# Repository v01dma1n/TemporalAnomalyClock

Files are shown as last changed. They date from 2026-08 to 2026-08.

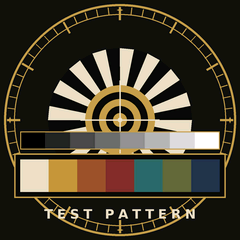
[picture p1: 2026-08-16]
images/photo_face_test_signal.png

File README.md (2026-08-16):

# Temporal Anomaly Clock

An ESP-IDF firmware for a round GC9A01 LCD turned NTP clock with a
twist: the displayed time doesn't just tell you the time, it visibly
speeds up, slows down, and occasionally runs backwards — while staying
exactly correct on average.

This is the IDF port of the Arduino-generation `temporal_anomaly_clock`
(originally a MAX6921-driven VFD tube clock), rebuilt on top of
[ESP32NTPClock2](https://github.com/v01dma1n/ESP32NTPClock2) and
[ESP32WiFi2](https://github.com/v01dma1n/ESP32WiFi2), aligned with the
architecture used by [MoodWhisperer](https://github.com/v01dma1n/MoodWhisperer).
Class names, extension points, and file layout mirror that project, so
switching between the two should feel familiar. The VFD tube is gone —
this generation targets a round pixel LCD instead — but the WiFi/NTP/
preferences engine underneath is the same one.

---

## Hardware

| Part | Role |
|---|---|
| ESP32-C3-MINI-1U | MCU (JCZN "ESP32-2424S012"-style integrated board) |
| GC9A01 | 1.28", 240×240 round IPS LCD, SPI |

Pinout (confirmed working on this board — no dedicated RST line, no
built-in touch used):

| Signal | GPIO |
|---|---|
| SPI SCLK | 6 |
| SPI MOSI | 7 |
| SPI CS | 10 |
| SPI DC | 2 |
| Backlight | 3 |
| RST | not connected — software reset only |

The panel needs a horizontal mirror at the LVGL display-config level
(`disp_cfg.rotation.mirror_x = true` in `disp_driver_gc9a01_round_clock.cpp`)
to render right-reading. This must be set in the `lvgl_port_display_cfg_t`
struct itself — a separate `esp_lcd_panel_mirror()` call made before
`lvgl_port_add_disp()` gets silently overwritten, since that function
re-applies orientation from `disp_cfg.rotation` internally.

---

## Project layout

```
TemporalAnomalyClock/
├── CMakeLists.txt
├── sdkconfig.defaults
├── partitions/
│   └── partitions.csv
├── components/
│   ├── esp32_ntp_clock/         # git submodule → ESP32NTPClock2 (the "engine")
│   ├── esp32_wifi/              # git submodule → ESP32WiFi2 (WiFi + prefs + portal)
│   └── esp32_ntp_clock_drivers/ # git submodule → ESP32NTPClockDrivers2
│       └── gc9a01/              # only this nested component is used — see below
└── main/                   # the application
    ├── main.cpp
    ├── temporal_anomaly_app.{h,cpp}
    ├── temporal_anomaly_preferences.{h,cpp}
    ├── temporal_anomaly_access_point_manager.{h,cpp}
    └── temporal_anomaly_time_source.{h,cpp}   # the "anomaly" itself — see Architecture
```

The GC9A01 display driver itself (`DispDriverGc9a01RoundClock`) and the
generic `IDisplayTimeProvider` interface it implements both live in the
shared [ESP32NTPClockDrivers2](https://github.com/v01dma1n/ESP32NTPClockDrivers2)
repo, under its `gc9a01/` nested component — not in `main/`. That
component is LVGL-based, unlike every other driver in that shared repo,
so it's kept separate and only pulled in by projects that explicitly opt
in (see that repo's README and this project's top-level `CMakeLists.txt`
for the `EXTRA_COMPONENT_DIRS`/`EXCLUDE_COMPONENTS` wiring this needs).

---

## Architecture

### 1. Engine (`components/esp32_ntp_clock`, `components/esp32_wifi`)

Same engine as MoodWhisperer: `BaseNtpClockApp`, `ClockFsmManager`,
`SceneManager`, `IDisplayDriver`, `BasePreferences`,
`BaseAccessPointManager`. See either project's submodule source for the
full interface surface — nothing about it is modified here.

### 2. Display driver (`components/esp32_ntp_clock_drivers/gc9a01/`)

`DispDriverGc9a01RoundClock` is deliberately generic and reusable — it has
no notion of "temporal anomaly," wobble, or chaos. It has two jobs on one
physical screen:

- **`IDisplayDriver` implementation** — satisfies the engine's
  character-grid contract (`setChar`, segment masks, frame buffers) so
  the boot/WiFi/NTP/AP-mode status messages the engine already knows how
  to generate keep working unmodified. There's no real segment glass
  behind it: the plain-text path just pushes to an LVGL status label.
  Segment-specific methods are accepted but no-op — nothing in this app
  drives segment-style scene animations (the `SceneManager` playlist is
  empty).
- **The watch face** — an analog clock (hour/minute/second hands as
  `lv_line` widgets, tight-bounding-box sized per update rather than
  full-screen, to keep SPI traffic and redraw regions small) plus a
  six-slot digital readout (one `lv_label` per digit, since proportional
  font glyphs aren't equal-width and a single shared label visibly
  drifts sideways as digits change).

The two live on separate LVGL screens (`_bootScreen` / `_faceScreen`),
switched via `lv_scr_load()`. `showClockFace()` flips between them once
the FSM reaches `RUNNING_NORMAL`.

Each tick, the driver just asks *"what time is it"* via a small interface
it defines and owns no opinion about the answer to:

```cpp
// i_display_time_provider.h
struct DisplayTime { int hour, minute; double second; int wday, mday; };
class IDisplayTimeProvider {
public:
    virtual DisplayTime getDisplayTime() = 0;
};
```

`setTimeProvider(IDisplayTimeProvider*)` wires in whatever answers that
question. A different app could plug in a provider that just calls
`localtime_r()` on real time and get an ordinary accurate clock out of
this same driver, unmodified.

### 3. The anomaly (`main/temporal_anomaly_time_source.{h,cpp}`)

`TemporalAnomalyTimeSource : IDisplayTimeProvider` is what actually makes
this clock a *temporal anomaly* clock rather than a plain one — the
sinusoidal wobble and the chaos levels (see below) both live here,
entirely decoupled from LVGL/rendering. `TemporalAnomalyClockApp` owns the
instance and wires it into the display driver in `setupHardware()`.

### 4. Application (`main/temporal_anomaly_*`)

- `TemporalAnomalyPreferences : BasePreferences` — adds startup-animation
  toggle, OpenWeatherMap key/city, and the anomaly wobble period/amplitude
  on top of `BaseConfig`.
- `TemporalAnomalyAccessPointManager : BaseAccessPointManager` — adds the
  matching rows to the captive portal.
- `TemporalAnomalyClockApp : BaseNtpClockApp` — owns the display driver,
  the time source, the display manager, and the shared `WeatherManager`.
  No scene playlist; `loop()` toggles `showClockFace()` directly off FSM
  state and feeds fresh weather readings into the display driver each
  tick.

---

## The temporal anomaly

The watch face's *displayed* time fluctuates — speeding up, slowing
down, and occasionally running backwards — while staying exactly
correct on average. Modeled as a sinusoidal rate around real time:

```
rate(t) = 1 + A·sin(2π·t/P)
```

Integrating that rate gives the displayed-time offset from real time,
which is periodic with period `P`. Whenever `P` evenly divides 60, the
offset at `t+60` exactly equals the offset at `t` — meaning displayed
time gains exactly as much as it loses over *any* 60-second window, not
just ones aligned to a particular phase. This holds regardless of
amplitude: with `A > 1` the rate swings negative for part of each cycle
and the hands visibly reverse before catching back up.

Configurable in the portal:

- **Anomaly wobble period (sec)** — should divide 60 evenly (e.g. 5, 6,
  10, 12, 15, 20, 30, 60) for the exact-average guarantee; not enforced
  by the form.
- **Anomaly wobble amplitude ×100** — 100 = steady real time, >100 lets
  the hands run backwards for part of each cycle. Default 140 (rate
  swings from −0.4x to 2.4x).

Only the watch-face rendering is perturbed — real system time (NTP
sync, logs, preferences, `time()`) is untouched.

---

## Chaos anomaly levels

A second, independent perturbation layered additively on top of the
sinusoidal wobble above. Unlike that system, chaos mode makes **no**
accuracy guarantee — it's a damped random walk, not a periodic
function:

- occasional random "kicks" to a velocity, with probability and
  magnitude both scaling with level (so low levels stutter rarely,
  high levels kick often and hard), hard-capped so a run of
  same-direction kicks can't accumulate into runaway speed;
- weak mean-reversion pulling that velocity back toward zero — more
  weakly at higher levels, so excursions last longer as the level
  increases;
- a gentle spring pulling the accumulated offset back toward real
  time, so even at max chaos the clock stays roughly near real time
  over long periods without any hard guarantee.

Configurable in the portal:

- **Anomaly chaos level (0-11)** — 0 off, 1-3 subtle speed variations
  and occasional skips/repeats, 4-7 noticeable accelerations/
  decelerations/short reversals, 8-10 extreme and largely
  unpredictable speed changes, 11 fully random — the displayed second
  is re-rolled to a random 0-59 value once per real elapsed second
  (hour/minute keep tracking real time; only the second progression
  goes chaotic).

Both perturbation systems only affect the watch-face rendering, same
as the sinusoidal wobble — real system time is never touched.

### Why the hands are flat, not tapered

The hands were originally drawn as 6 stacked line segments per hand
(18 total) to fake a tapered width + color gradient — `lv_line` can't
taper or gradient a single stroke natively. Under fast chaos motion
this became a real bottleneck: measurement showed LVGL ticks meant to
fire every 30ms were arriving 150-300ms late *even at chaos level 0*,
meaning the redraw cost is a constant per-tick problem that's simply
invisible when the hand barely moves between frames. Neither raising
the SPI clock (20→40MHz) nor disabling the dial's live gradient
background changed this — cutting the segment count from 6 to 1 per
hand did, roughly 3x. Hands are now a single flat-color segment each;
this MCU/display combo has a real throughput ceiling well under the
30Hz the tick timer assumes.

---

## Weather

Pulls current temperature (°F) and relative humidity from
[OpenWeatherMap](https://openweathermap.org/) via the shared
`WeatherManager`, and rotates them into the digital readout row every
5 seconds alongside the time (`TIME → TEMPERATURE → HUMIDITY → TIME →
...`). The analog hands keep ticking continuously regardless of what
the readout row is showing.

Configure in the portal:

- **OpenWeatherMap API Key** — free account at openweathermap.org.
- **OWM City** — comma-separated as the OWM API expects, e.g.
  `South Plainfield,NJ,US` or `Warsaw,PL`. A plain space instead of
  commas will fail to geocode (404).

The temperature/humidity rotation stays on TIME only until the first
successful fetch — it never shows stale or zeroed weather.

---

## Photo face

A fourth rotation slot alongside TIME/TEMPERATURE/HUMIDITY: full-face
240×240 images (`main/photo_face_*_data.cpp`, round-robin via
`setPhotos()`) with a one-pass CRT-style scan-bar sweep and flicker,
wired in via `DispDriverGc9a01RoundClock`. The driver itself has no
opinion on the images' content — same generic seam as
`IDisplayTimeProvider` — so swapping in a different photo is just a
matter of running `scripts/convert_photo.py path/to/image.jpg
var_name photo_face.h` against a new square source image and
rebuilding. Most of the rotation is Google Gemini-generated portraits;
the "test signal" slot (`photo_face_test_signal`) is instead a
code-synthesized art-deco TV test card (PIL, see
`scripts/gen_deco_test_card.py`), not AI-generated art.

---

## Captive portal and timezone handling

Same split as MoodWhisperer:

1. First boot / no credentials stored → AP mode → user enters SSID/
   password and picks a timezone from the dropdown (defaults to UTC).
2. After WiFi connects, `ClockFsmManager` tries automatic timezone
   detection via IP geolocation if the stored timezone is blank, but
   the portal always has the final say.

The portal is open (no password) at `http://192.168.4.1/`, with every
DNS query on the AP network redirected there so phones/laptops pop the
captive-portal sheet automatically.

This app doesn't wire up a physical AP-trigger button (unlike
MoodWhisperer's BOOT-button hold) — the only way to force AP mode is
`BootManager`'s built-in double-reset detection: two resets within
~10 seconds. Worth knowing when iterating with `idf.py flash` followed
by a manual reset for testing — back-to-back resets land you in the
portal.

---

## Build

Requirements: ESP-IDF ≥ 5.1, targeting `esp32c3`.

The `components/esp32_ntp_clock`, `components/esp32_wifi`, and
`components/esp32_ntp_clock_drivers` directories are git submodules.
Initialise them after cloning:

```bash
git clone --recurse-submodules https://github.com/v01dma1n/TemporalAnomalyClock.git
# or, inside an existing clone:
git submodule update --init
```

Then build and flash:

```bash
. $IDF_PATH/export.sh
cd TemporalAnomalyClock
idf.py set-target esp32c3
idf.py build
idf.py -p /dev/ttyACM0 flash
```

`idf.py monitor` needs an interactive TTY; from a non-interactive shell,
read the serial port directly (e.g. via `pyserial`) instead.

First boot: the board comes up in AP mode (no credentials stored).
Connect to the open `temporal-anomaly` network, the captive portal
opens, fill in WiFi + timezone + (optionally) OpenWeatherMap + anomaly
wobble settings, save.

---

## Known issues

- No external RTC on this board — NTP-only timekeeping. Per
  MoodWhisperer's own notes on the same engine: an NTP timeout with no
  RTC fitted can drop the FSM back into AP_MODE even when WiFi is up
  (`clock_fsm_manager.cpp`, `NTP_SYNC` case). Not yet reproduced on this
  project, but worth knowing if the clock ever seems to bounce back to
  setup mode unexpectedly on a flaky network.
- The "anomaly level" field in the original Arduino app's preferences
  was dead code there (stored but never actually read). The chaos
  levels feature (above) reuses the name but is a from-scratch
  implementation with real behavior behind it, not a revival of that
  old field.

---

## License

MIT (matches the upstream Arduino projects and MoodWhisperer).

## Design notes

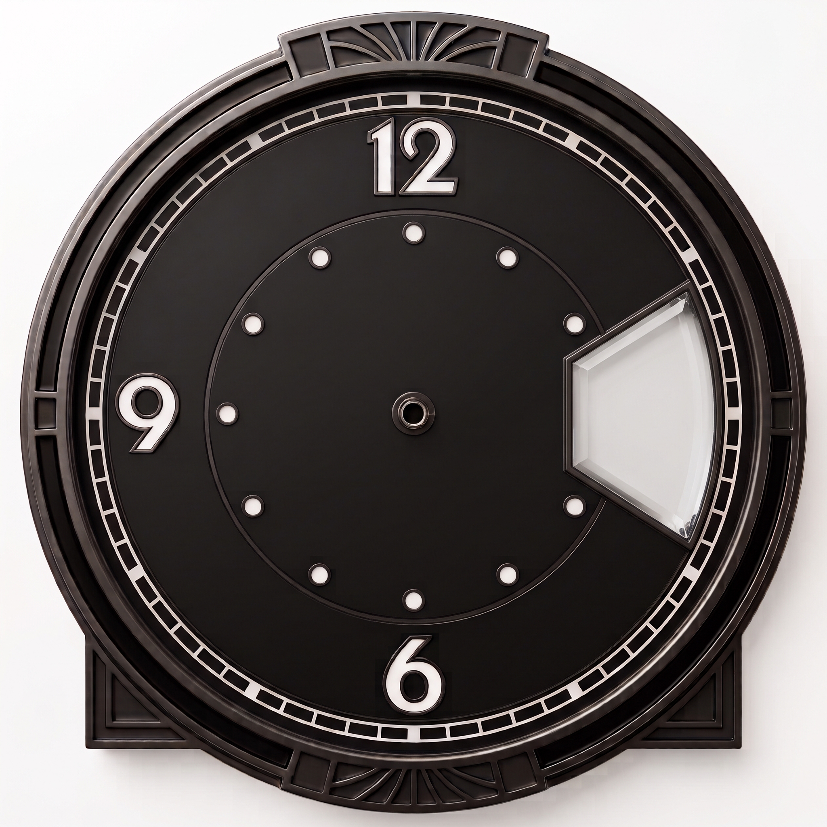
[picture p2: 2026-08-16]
images/input/Gemini_Generated_Image_clock_face_no_arms_date_crystal.jpeg

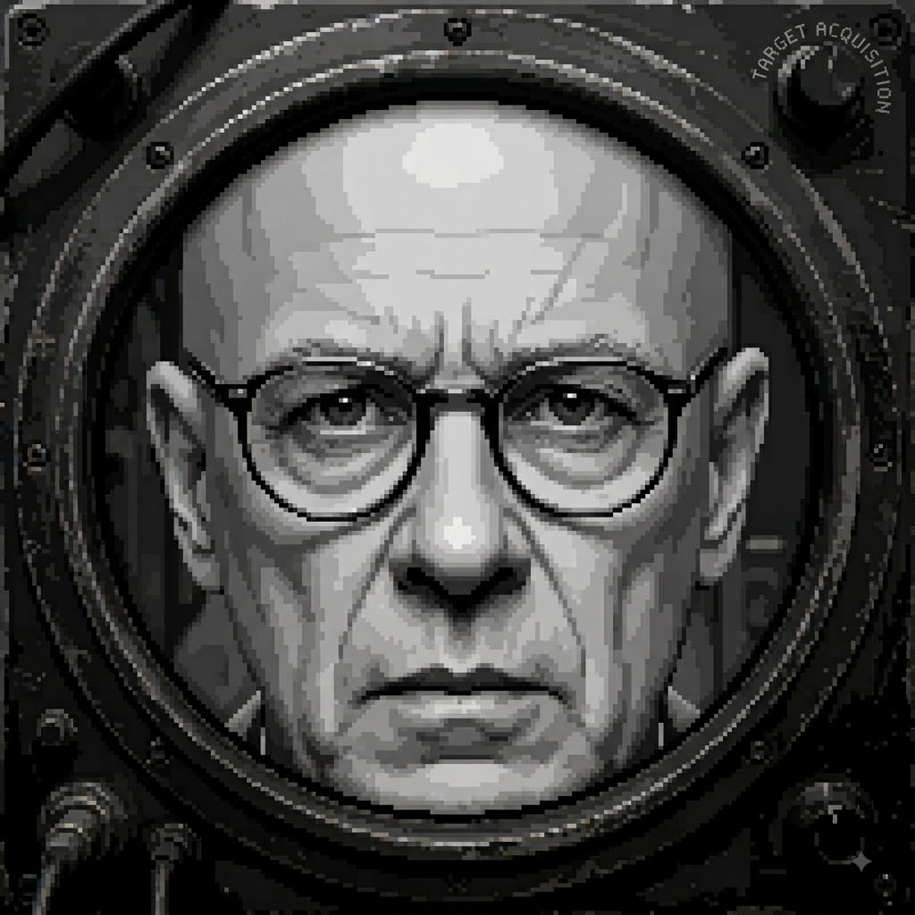
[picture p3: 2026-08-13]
images/input/Gemini_Generated_bald_man.jpeg

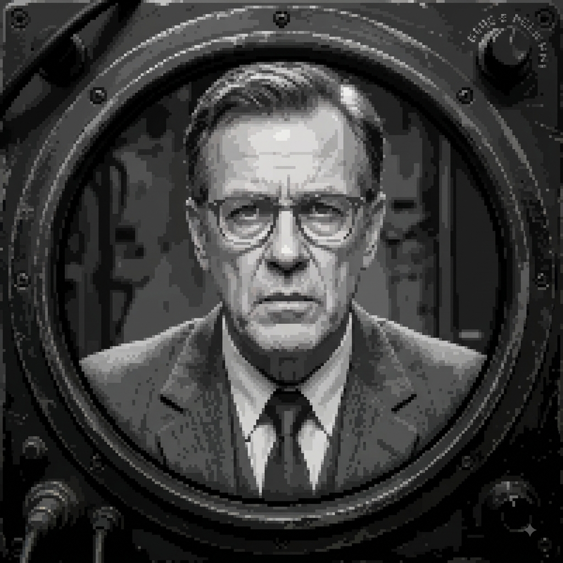
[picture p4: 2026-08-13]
images/input/Gemini_Generated_Image_wl5qerwl5qerwl5q.png

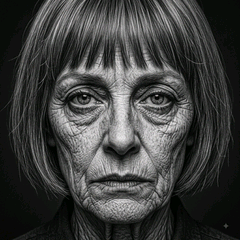
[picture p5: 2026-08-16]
images/photo_face_warden.png

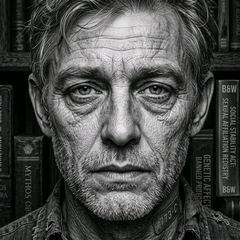
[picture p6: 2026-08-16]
images/photo_face_archivist.png

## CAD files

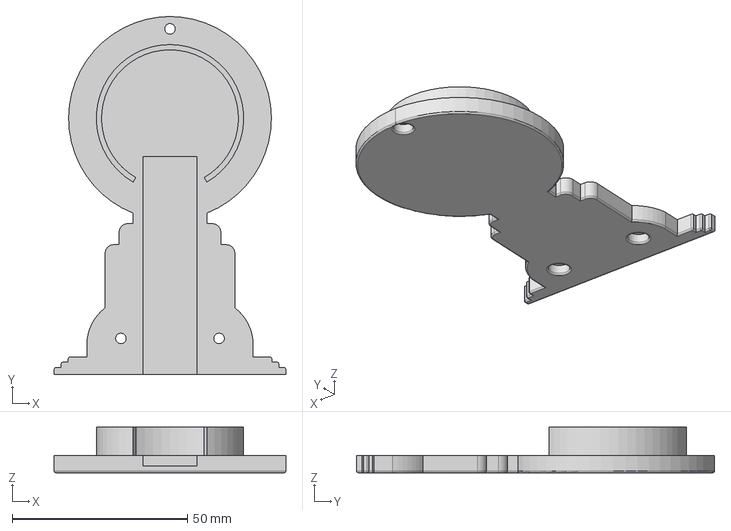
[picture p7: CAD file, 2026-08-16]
print3d/Temporal Anomaly Back - V19 PCB Holder Larger Diam.step
66.0 x 102.0 x 13.0 mm

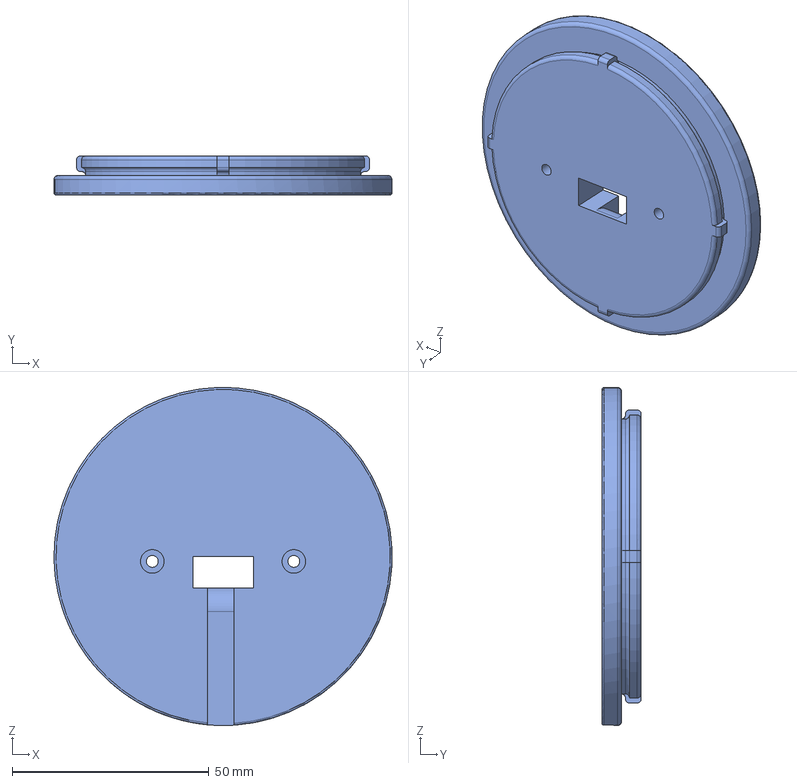
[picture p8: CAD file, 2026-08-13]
print3d/Temporal Anomaly Base - V15 Narroware.step
86.0 x 10.0 x 86.0 mm

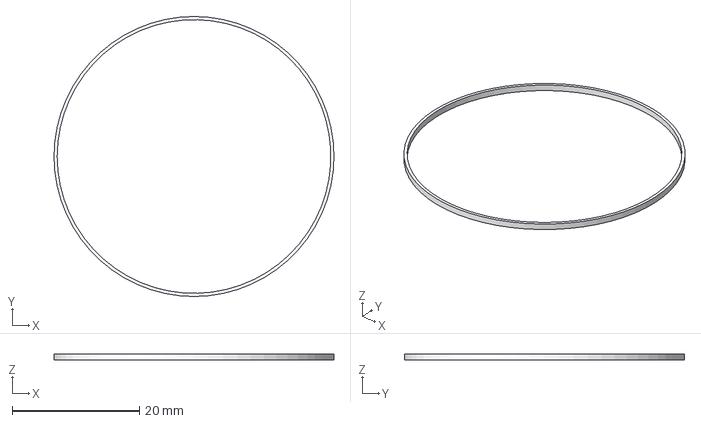
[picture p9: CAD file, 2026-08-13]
print3d/Temporal Anomaly Lens Spacer - V7.step
44.0 x 44.0 x 1.00 mm

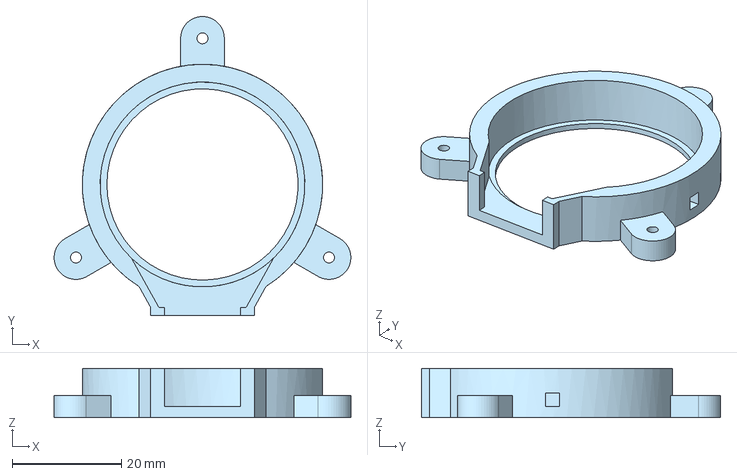
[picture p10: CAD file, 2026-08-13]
print3d/Temporal Anomaly DisplayCase - V7.step
54.3 x 54.7 x 9.00 mm

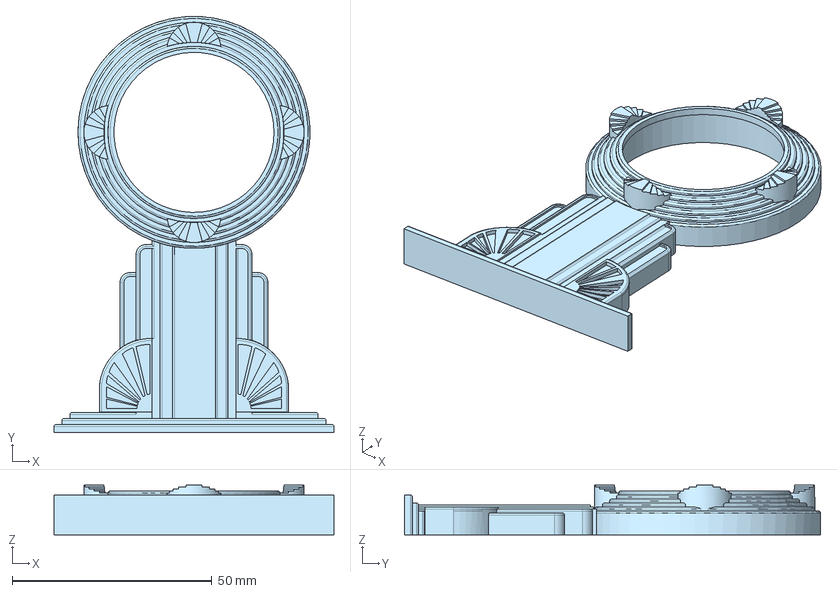
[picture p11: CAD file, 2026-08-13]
print3d/Temporal Anomaly Body - V10 Base and Crown.step
70.0 x 104.0 x 12.5 mm

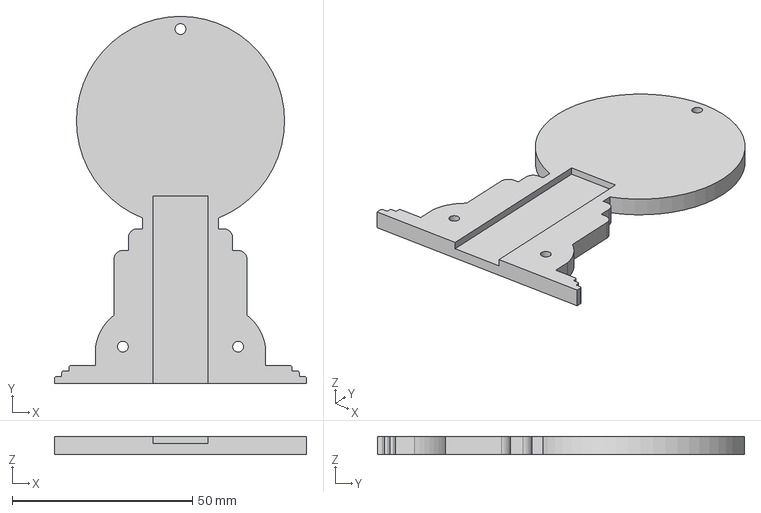
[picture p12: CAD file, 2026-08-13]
print3d/Temporal Anomaly Back - V12 Back and Base.step
70.0 x 102.0 x 5.00 mm

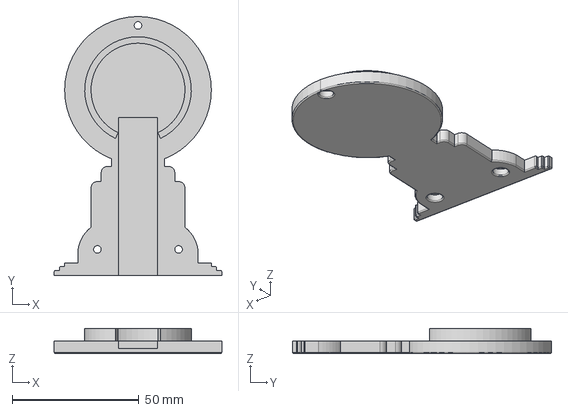
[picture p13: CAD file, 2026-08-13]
print3d/Temporal Anomaly Back - V15 Narroware.step
66.0 x 102.0 x 10.0 mm

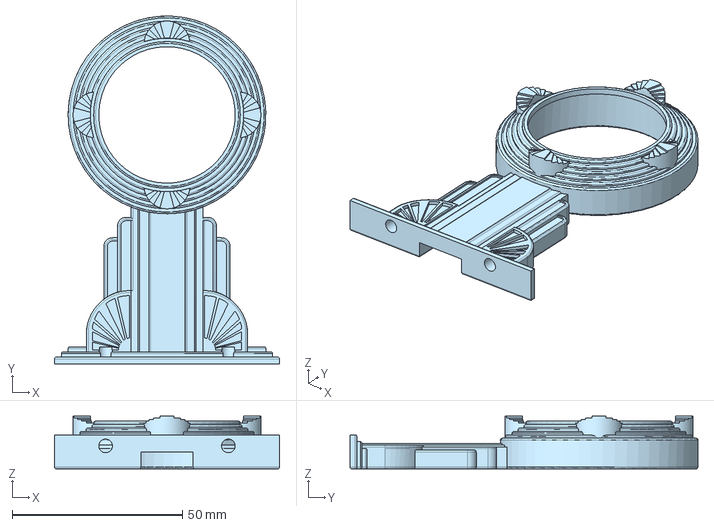
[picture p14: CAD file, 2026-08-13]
print3d/Temporal Anomaly Body - V16 Depth Increased.step
66.0 x 102.0 x 15.5 mm

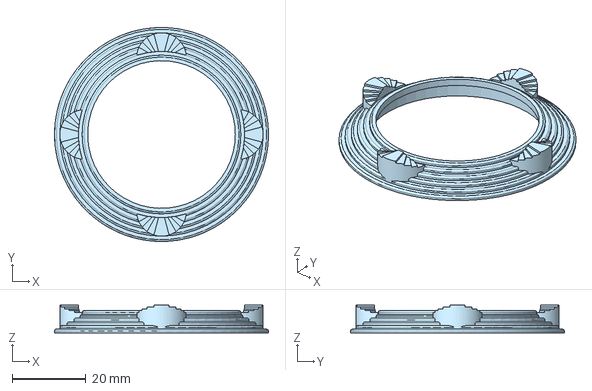
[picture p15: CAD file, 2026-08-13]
print3d/Temporal Anomaly Body - V9 Crown.step
58.0 x 58.0 x 7.50 mm

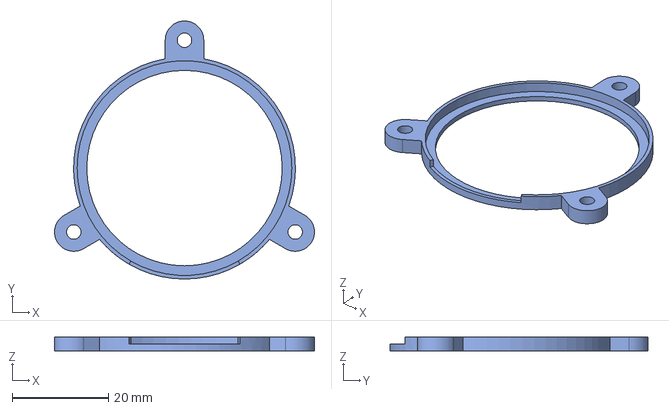
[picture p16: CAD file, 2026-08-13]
print3d/Temporal Anomaly Lens Mount - V7.step
53.9 x 53.5 x 3.00 mm

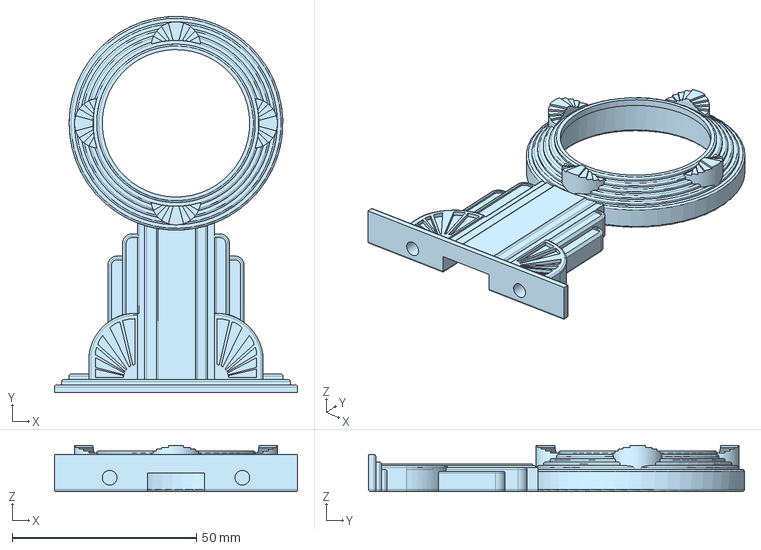
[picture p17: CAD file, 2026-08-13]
print3d/Temporal Anomaly Body - V15 Narroware.step
66.0 x 102.0 x 12.5 mm

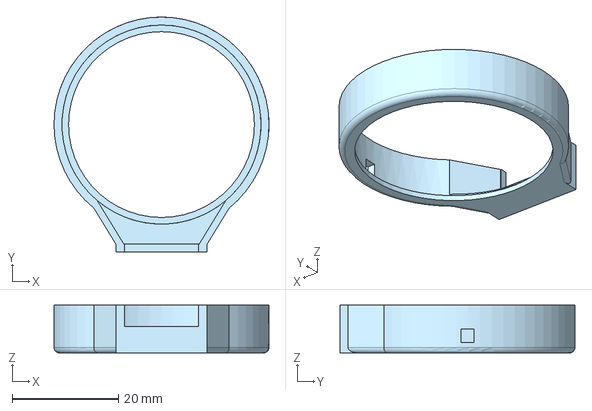
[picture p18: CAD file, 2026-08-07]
print3d/Temporal Anomaly DisplayCase - V3 Display Case thicker.step
40.5 x 44.2 x 9.00 mm

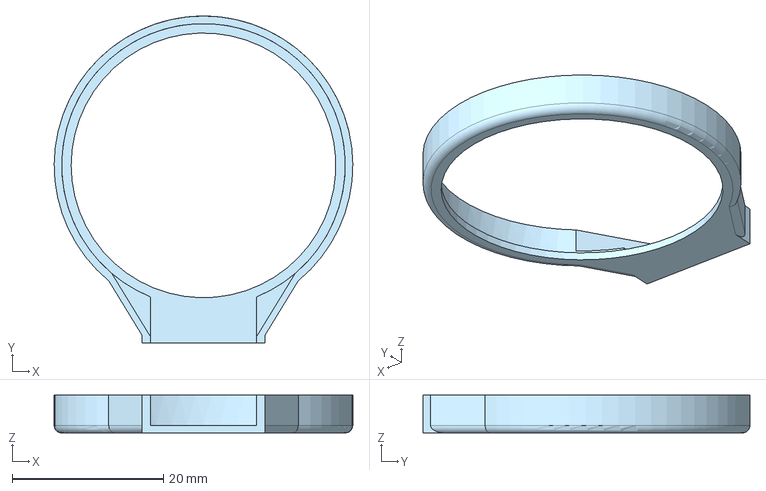
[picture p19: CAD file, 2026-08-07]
print3d/Temporal Anomaly DisplayCase - V2 Bezel Test V2.step
39.5 x 43.2 x 5.00 mm

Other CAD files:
print3d/Temporal Anomaly Base - V12 Back and Base.step
print3d/Temporal Anomaly Back - V16 Depth Increased.step
print3d/Temporal Anomaly Body - V12 Back and Base.step
print3d/Temporal Anomaly DisplayCase - V5 Fixed Overlap.step
print3d/Temporal Anomaly Lens Mount - V5 Fixed Overlap.step
print3d/Temporal Anomaly DisplayCase - V1 Display Case Test.step
print3d/Temporal Anomaly DisplayCase - V4 Lens Mount.step
print3d/Temporal Anomaly DisplayCase - V6.step
print3d/Temporal Anomaly Lens Mount - V4 Lens Mount.step
print3d/Temporal Anomaly Lens Mount - V6.step

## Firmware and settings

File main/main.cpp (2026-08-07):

// main.cpp — ESP-IDF entry point for TemporalAnomalyClock.
//
// Task layout (single-core ESP32-C3, so no PinnedToCore split like
// MoodWhisperer's dual-core ESP32-WROOM):
//   AppTask     — setup() + loop(): WiFi, NTP, portal, FSM.
//   DisplayTask — pumps DisplayManager::update() at ~5 Hz so the
//                 boot/status text (WiFi connect, NTP sync, AP mode)
//                 keeps refreshing even while AppTask is blocked inside
//                 activateAccessPoint()'s runBlockingLoop(). The watch
//                 face itself doesn't need this: it's driven by its own
//                 LVGL timer inside DispDriverGc9a01RoundClock once
//                 shown, same as MoodWhisperer's VFD needed a much
//                 faster DisplayTask (50 Hz) to multiplex digits — our
//                 display isn't multiplexed, so 5 Hz is plenty for text.

#include "temporal_anomaly_app.h"
#include "logging.h"

#include "nvs_flash.h"
#include "esp_netif.h"
#include "esp_event.h"
#include "freertos/FreeRTOS.h"
#include "freertos/task.h"

static constexpr int APP_TASK_STACK = 8192;
static constexpr int APP_TASK_PRIO  = 5;

static constexpr int DISPLAY_TASK_STACK = 4096;
static constexpr int DISPLAY_TASK_PRIO  = 4;

static void displayTask(void* /*pvParameters*/) {
    TemporalAnomalyClockApp& app = TemporalAnomalyClockApp::getInstance();
    DisplayManager& dm = app.getClock();
    for (;;) {
        dm.update();
        vTaskDelay(pdMS_TO_TICKS(200));
    }
}

static void appTask(void* /*pvParameters*/) {
    auto& app = TemporalAnomalyClockApp::getInstance();
    app.setup();

    xTaskCreate(displayTask, "DisplayTask", DISPLAY_TASK_STACK, nullptr,
                DISPLAY_TASK_PRIO, nullptr);

    for (;;) {
        app.loop();
        vTaskDelay(pdMS_TO_TICKS(10));
    }
}

extern "C" void app_main(void) {
    LOGINF(">>> TemporalAnomalyClock booting");

    esp_err_t err = nvs_flash_init();
    if (err == ESP_ERR_NVS_NO_FREE_PAGES ||
        err == ESP_ERR_NVS_NEW_VERSION_FOUND) {
        ESP_ERROR_CHECK(nvs_flash_erase());
        ESP_ERROR_CHECK(nvs_flash_init());
    } else {
        ESP_ERROR_CHECK(err);
    }

    ESP_ERROR_CHECK(esp_netif_init());
    ESP_ERROR_CHECK(esp_event_loop_create_default());

    xTaskCreate(appTask, "AppTask", APP_TASK_STACK, nullptr, APP_TASK_PRIO, nullptr);

    LOGINF(">>> tasks running; app_main returning to idle");
}

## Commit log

2025-10-23 gridMap moved to .ino out of the driver
2025-10-23 Font and pin mapping refactored
2026-08-06 Port to ESP-IDF C++ targeting the round GC9A01 LCD, replacing the VFD
    Full rewrite from the Arduino/MAX6921-VFD generation to ESP-IDF C++,
    aligned with MoodWhisperer's architecture (shared ESP32NTPClock2 +
    ESP32WiFi2 submodules, BaseNtpClockApp/IWeatherClock, same file-naming
    conventions). The round GC9A01 LCD replaces the VFD entirely, driven by
    a new DispDriverGc9a01RoundClock that bridges the engine's character-grid
    IDisplayDriver contract to an LVGL status label during boot, then hands
    off to an analog + digital watch face once the clock reaches
    RUNNING_NORMAL.
    Also includes the follow-up work done once the port was confirmed
    booting: a display horizontal-mirror orientation fix
    (disp_cf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
    [partitions.csv]
2026-08-07 Watch face realism pass: minute ticks, tapered hands, sunburst dial
    - Add 60 minute ticks (short, thin) filling the 48 positions between
    the existing 12 hour ticks.
    - Switch hands from single uniform-width lines to 3 stacked segments
    of decreasing width (base/mid/tip) for a tapered "sword hand" look —
    LVGL lines can't taper a single stroke, so each hand is now
    createTaperedHand()/setTaperedHand() driven instead of the old
    single-object createHand()/setHand().
    - Add a subtle sunburst dial: radial gradient background (warm dark
    center fading to black at the bezel) via LVGL 9's native radial
    gradient support. Needed CONFIG_LV_USE_DRAW_SW_COMPLEX_GRADIENTS,
    off by default.
    Co-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
2026-08-07 Add chaos anomaly levels (0-11) and fix chaos-mode render lag
    Chaos levels layer a damped random walk on top of the existing
    sinusoidal wobble, selectable via the AP portal (anom_level 0-11:
    0 off, 1-3 subtle, 4-7 noticeable, 8-10 extreme, 11 fully random
    seconds). Unlike the sinusoidal wobble this makes no 60s-accuracy
    guarantee, per design.
    Measured (not guessed) the reported "hands not straight / drawing
    slow" complaint under fast chaos motion: ticks meant to fire every
    30ms were arriving 150-300ms apart even at chaos level 0, so the lag
    was a constant per-tick rendering cost, just imperceptible at normal
    speed. Ruled out SPI clock (20->40MHz, no change) and the dial's live
    gradient back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
2026-08-07 Extract time-variation logic out of the display driver
    DispDriverGc9a01RoundClock previously owned both the generic round-LCD
    watch face rendering AND the temporal-anomaly time math (sinusoidal
    wobble + chaos levels), making it unreusable outside this one app.
    Split via a new tiny interface, IDisplayTimeProvider
    (i_display_time_provider.h): the driver now just asks "what time is
    it" each tick and renders whatever DisplayTime it gets back, with no
    opinion on where that came from. TemporalAnomalyTimeSource
    (temporal_anomaly_time_source.{h,cpp}) implements that interface and
    is where the wobble/chaos math now lives, unchanged in behavior —
    TemporalAnomalyClockApp owns the instance and wires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
2026-08-07 Move display driver to shared repo; rename project to TemporalAnomalyClock
    DispDriverGc9a01RoundClock and IDisplayTimeProvider move out of main/
    into ESP32NTPClockDrivers2's new gc9a01/ nested component (added here
    as a git submodule) -- the driver is now genuinely reusable, with no
    knowledge of this app's wobble/chaos logic (that stays local, in
    TemporalAnomalyTimeSource). Required two non-obvious additions to the
    top-level CMakeLists.txt: EXTRA_COMPONENT_DIRS pointing directly at
    the gc9a01/ subdirectory (not the submodule root), and
    EXCLUDE_COMPONENTS to skip the submodule root's own top-level
    component, which pulls in build dependencies (lgl_vfd_studio) specific
    to its other consumers.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
    [Temporal Anomaly DisplayCase - V1 Display Case Test.step, Temporal Anomaly DisplayCase - V2 Bezel Test V2.step, Temporal Anomaly DisplayCase - V3 Display Case 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]
2026-08-07 Add anomaly rate gauge to the watch face
    TemporalAnomalyTimeSource::lastRateDeviation() computes the
    instantaneous deviation from 1.0x real-time speed (sinusoidal wobble's
    rate contribution, A*sin(phase), plus the chaos walk's current
    velocity), fed into the display driver's new setRateGauge() every
    loop() tick. Bumps the esp32_ntp_clock_drivers submodule to pick up
    that new driver feature.
    Also adds V5 print3d case/lens-mount design files (fixed overlap from
    V4).
    Confirmed working on hardware: gauge position/orientation, needle
    motion under both normal wobble and chaos levels, tick mark colors,
    and backing-disc styling all iterated and approved visually.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
    [Temporal Anomaly DisplayCase - V5 Fixed Overlap.step, Temporal Anomaly Lens Mount - V5 Fixed Overlap.step]
2026-08-13 Add photo face mode with CRT scan-bar/flicker distortion
    Wires DispDriverGc9a01RoundClock::setPhoto() up with a converted
    240x240 RGB565 portrait (photo_face_data.cpp, generated from the
    source JPEG by a one-off conversion script) shown in the face-mode
    rotation; the driver-side scan-bar/flicker effect lives in the
    ESP32NTPClockDrivers2 submodule bump. Also picks up the print3d V6/V7/
    V9/V10/V12/V15/V16 case iterations and reference photos.
    [Temporal Anomaly Back - V12 Back and Base.step, Temporal Anomaly Back - V15 Narroware.step, Temporal Anomaly Back - V16 Depth Increased.step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]
2026-08-13 Alternate three photos in photo mode, add Google Gemini attribution
    Wires the driver's new setPhotos() round-robin up with three portraits
    (man/librarian/archivist) instead of one static image. Adds
    scripts/convert_photo.py (parameterized on source + C identifier) as
    the actual repo-tracked conversion tool, replacing the one-off
    scratchpad version, and credits Google Gemini as the source generator
    in the README, photo_face.h, and each generated data file's header
    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
2026-08-14 Bump ESP32NTPClockDrivers2: grayscale clock face + scan-matched reveal
2026-08-14 Bump ESP32NTPClockDrivers2: add CRT scanline overlay to the face screen
2026-08-16 Static art-deco dial, photo rotation rename, asset reorg
    Bump ESP32NTPClockDrivers2: static dial background image support,
    30s TIME dwell, brighter hands, unified/retimed photo+reveal CRT
    effects, retired digital HH:MM:SS readout, weather-label guard.
    Bump ESP32NTPClock2: invalidate weather data when OWM key/city are
    unconfigured instead of leaving stale valid=true readings in place.
    App-level changes:
    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
    [Temporal Anomaly Back - V19 PCB Holder Larger Diam.step, partitions.csv]
2026-08-16 Add date-crystal dial background, enable montserrat_34
    Bump ESP32NTPClockDrivers2: move the date complication into the new
    dial art's faceted date window (day-of-month only, no weekday/month,
    larger dark text) instead of the old empty 3 o'clock spot.
    Regenerate the dial background from the new source image (date
    crystal in place of the "3" numeral) and enable
    CONFIG_LV_FONT_MONTSERRAT_34 for the larger date text.
2026-08-21 Bump esp32_ntp_clock_drivers: disable mirror_x for new GC9A01 board
    Claude-Session: https://claude.ai/code/session_01YAdgjbh3mgkknfp45RFe6W
2026-08-21 Bump esp32_ntp_clock_drivers: document open cold-boot mirror issue
    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
2026-08-21 Bump esp32_ntp_clock_drivers: fix cold-boot mirror (mirror_x=true)
    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
2026-08-21 Replace dial background with a dots-free variant
    The decorative dot ring in the previous dial background overlapped the
    temperature/humidity label and the brand text. Same pivot/crop as v5
    (1027,1018, half 900), regenerated from a new source with that ring
    removed.
    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
2026-08-21 Aged dial texture, startup splash, AP-connected instructions
    - Bake a subtle worn-metal grain into the dial background image
    (zero runtime cost, unlike the live noise overlays tried and
    discarded this session).
    - Queue the startup splash (app name/author/year) that was never
    actually set despite showStartupAnimation existing as a portal
    toggle; static banner, not scrolling -- scrolling doesn't suit a
    multi-line centered label. Duration now overridable per-app.
    - AP mode now switches its banner to browser-open instructions once a
    client actually associates, instead of only ever showing the
    join-network prompt.
    Claude-Sessi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
2026-08-21 Adopt git-derived firmware versioning, drop unused VER_MAJOR/MINOR/BUILD
    VER_MAJOR/MINOR/BUILD existed since the project's start and were never
    once bumped -- dead weight quietly lying about what's actually
    flashed. ESP-IDF already stamps every build with a git-describe string
    (CONFIG_APP_PROJECT_VER_FROM_CONFIG is unset, the default); this now
    surfaces that via esp_app_get_description()->version on a dedicated
    boot-screen footer (setVersionTag(), esp32_ntp_clock_drivers) instead.
    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
